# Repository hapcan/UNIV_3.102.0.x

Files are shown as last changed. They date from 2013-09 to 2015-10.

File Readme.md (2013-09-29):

UNIV 3.102.0.x
============

ETHERNET INTERFACE - interface to devices with Ethernet port (server mode)

Device webpage: http://hapcan.com/devices/universal/univ_3/univ_3-102-0-x/

Hardware created in Eagle PCB Software http://www.cadsoftusa.com/

Firmware created in Microchip MPLAB http://www.microchip.com/mplabide/ in assembly language
                 and
                 in Tibbo IDE http://tibbo.com/basic/product/tide.html in Tibbo Basic language

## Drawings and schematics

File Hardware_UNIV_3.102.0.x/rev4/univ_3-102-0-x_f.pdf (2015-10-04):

## ETHERNET INTERFACE

# UNIV 3.102.0.x

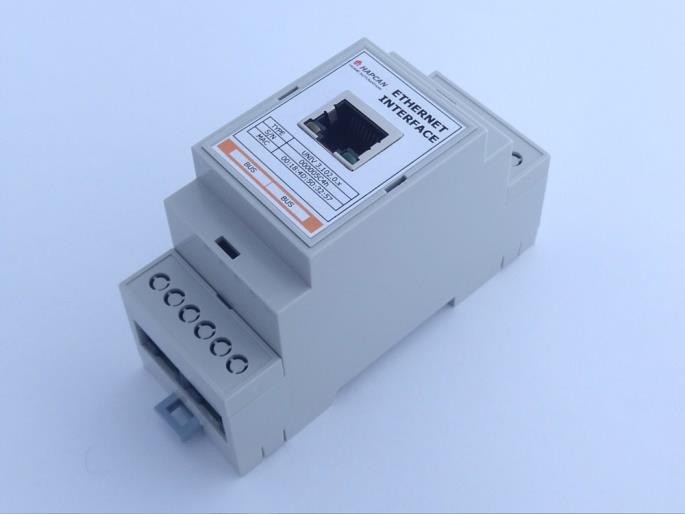
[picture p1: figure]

© 2014 hapcan.com | univ_3-102-0-x_f.pdf - page 1 / 5

### 1. Features

- Ethernet interface for HAPCAN system.
- Uses Tibbo miniature programmable Ethernet EM500 module
- 512kB build into Tibbo module and 1MB external flash memory for firmware; 200 bytes of EEPROM space for data storage
- Supports 10/100BaseTX
- Supports auto-MDIX
- Build in Real Time Clock
- Operation voltage 10-24V
- Current consumption 60mA
- For DIN rail mounting.
- Dimensions 90x58x36 mm (2 mod)
- Operating of module depends on firmwares uploaded into it (Tibbo and UNIV 3 firmwares)

### 2. Application version

UNIV | 3 | . | 102 | . | 0 | . | x
firmware version
application version
application type (Ethernet interface) processor version
universal processor

### 3. Technical data

Bus side
Parameter | Symbol | Value | Unit
Power supply voltage | Us | 10-24V | V
Current consumption | Is | 150@10V, 60@24V | mA
Bus connector type | 2x RJ45 connectors

Ethernet port side
Parameter | Unit
Connector | RJ45 auto-MDIX
Status LEDs | Bright LEDs flashing means active 10/100BaseTX link. Flashing patterns depend on firmware installed in Tibbo

### 4. Hardware

### 4.1. Wiring

1 - Tx+
2 - Tx-3 - Rx+
4 - NC

5 - NC
6 - Rx-7 - NC
8 - NC

Note that if module is first or last on the bus,
resistor 120ohm must be connected between pins CAN H and CAN L.
Figure 1. RJ45 10/100 BaseTX Ethernet connector. | Figure 2. RJ45 bus connector.
1 | 8
1 | 8
1 | 8

1 – white/orange - CAN H
2 – orange - CAN L
3 – white/green - NC
4 – blue – CAN V+
5 – white/blue – CAN GND
6 – green - NC
7 – white/brown – CAN GND
8 – brown – CAN V+

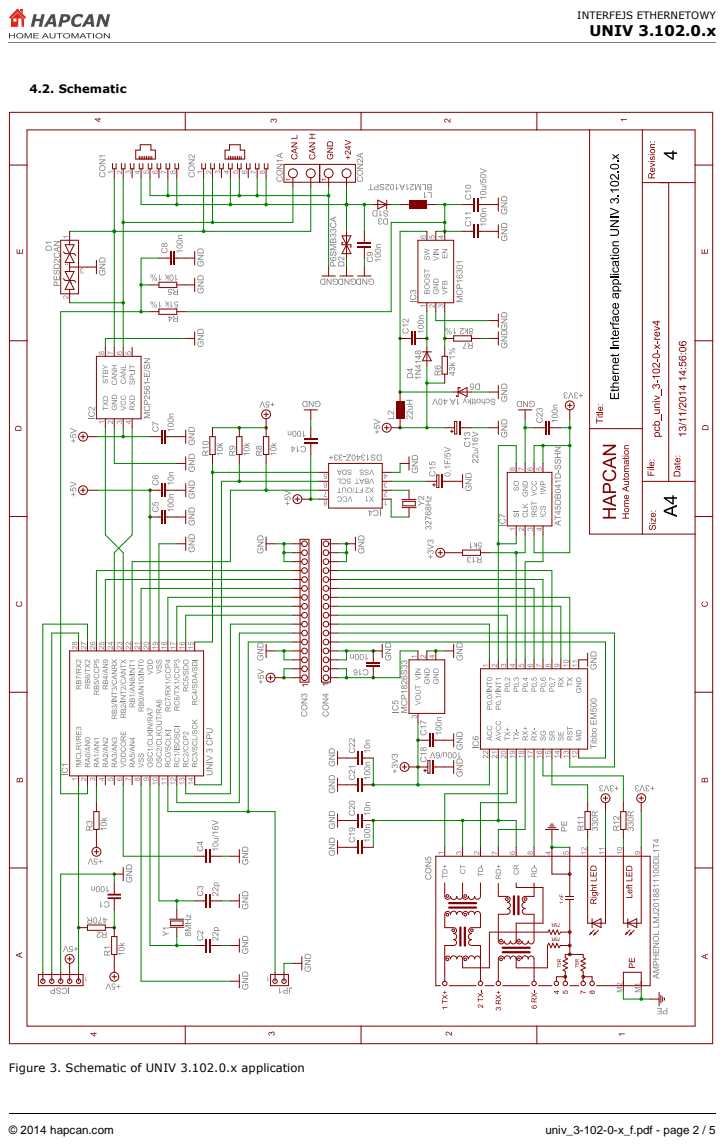
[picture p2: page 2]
INTERFEJS ETHERNETOWY; 4.2. Schematic

Figure 3. Schematic of UNIV 3.102.0.x application

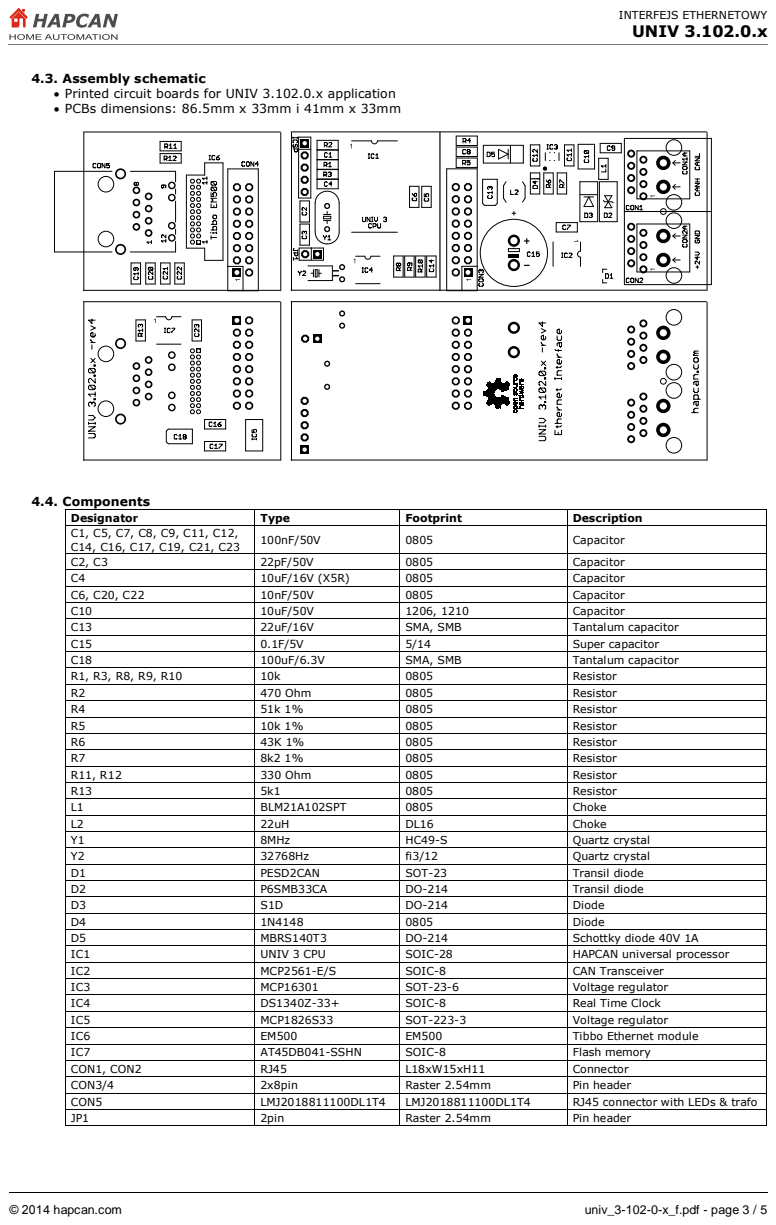
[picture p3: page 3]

4.3. Assembly schematic
• Printed circuit boards for UNIV 3.102.0.x application
• PCBs dimensions: 86.5mm x 33mm i 41mm x 33mm

Designator | Type | Footprint | Description
C1, C5, C7, C8, C9, C11, C12, C14, C16, C17, C19, C21, C23 | 100nF/50V | 0805 | Capacitor

C2, C3 | 22pF/50V | 0805 | Capacitor
C4 | 10uF/16V (X5R) | 0805 | Capacitor
C6, C20, C22 | 10nF/50V | 0805 | Capacitor
C10 | 10uF/50V | 1206, 1210 | Capacitor
C13 | 22uF/16V | SMA, SMB | Tantalum capacitor
C15 | 0.1F/5V | 5/14 | Super capacitor
C18 | 100uF/6.3V | SMA, SMB | Tantalum capacitor
R1, R3, R8, R9, R10 | 10k | 0805 | Resistor
R2 | 470 Ohm | 0805 | Resistor
R4 | 51k 1% | 0805 | Resistor
R5 | 10k 1% | 0805 | Resistor
R6 | 43K 1% | 0805 | Resistor
R7 | 8k2 1% | 0805 | Resistor
R11, R12 | 330 Ohm | 0805 | Resistor
R13 | 5k1 | 0805 | Resistor
L1 | BLM21A102SPT | 0805 | Choke
L2 | 22uH | DL16 | Choke
Y1 | 8MHz | HC49-S | Quartz crystal
Y2 | 32768Hz | fi3/12 | Quartz crystal
D1 | PESD2CAN | SOT-23 | Transil diode
D2 | P6SMB33CA | DO-214 | Transil diode
D3 | S1D | DO-214 | Diode
D4 | 1N4148 | 0805 | Diode
D5 | MBRS140T3 | DO-214 | Schottky diode 40V 1A
IC1 | UNIV 3 CPU | SOIC-28 | HAPCAN universal processor
IC2 | MCP2561-E/S | SOIC-8 | CAN Transceiver
IC3 | MCP16301 | SOT-23-6 | Voltage regulator
IC4 | DS1340Z-33+ | SOIC-8 | Real Time Clock
IC5 | MCP1826S33 | SOT-223-3 | Voltage regulator
IC6 | EM500 | EM500 | Tibbo Ethernet module
IC7 | AT45DB041-SSHN | SOIC-8 | Flash memory
CON1, CON2 | RJ45 | L18xW15xH11 | Connector
CON3/4 | 2x8pin | Raster 2.54mm | Pin header
CON5 | LMJ2018811100DL1T4 | LMJ2018811100DL1T4 | RJ45 connector with LEDs & trafo
JP1 | 2pin | Raster 2.54mm | Pin header

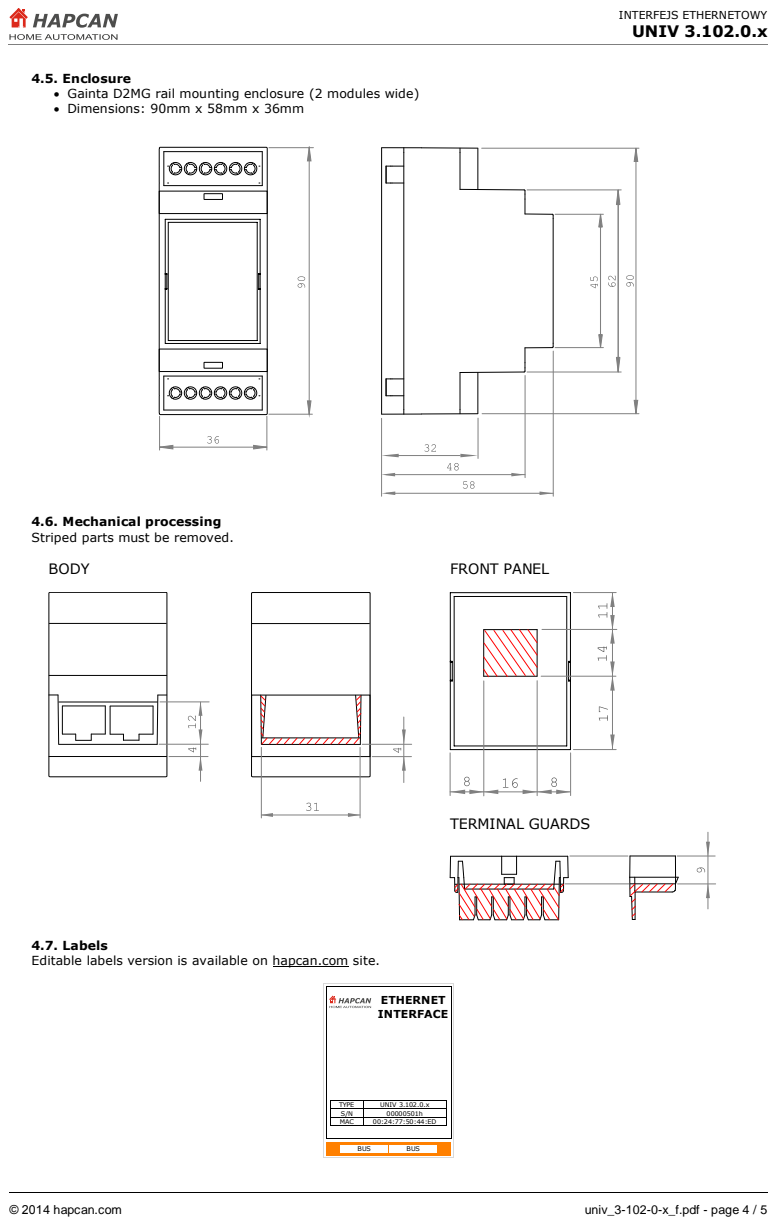
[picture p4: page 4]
BODY; FRONT PANEL; TERMINAL GUARDS; ETHERNET INTERFACE; BUS

4.5. Enclosure
• Gainta D2MG rail mounting enclosure (2 modules wide)
• Dimensions: 90mm x 58mm x 36mm

4.6. Mechanical processing
Striped parts must be removed.

4.7. Labels
Editable labels version is available on hapcan.com site.

TYPE | UNIV 3.102.0.x
S/N | 00000501h
MAC | 00:24:77:50:44:ED

### 5. Commissioning

### 5.1. CPU voltage measurement

After verifying the correctness and quality of the soldering, the bus voltage should be connected while measuring the processor voltage. To do this, connect a voltmeter to pins 2 and 3 of the ICSP connector. Processor supply voltage should be about 5V.

Figure 4. CPU voltage measurement
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

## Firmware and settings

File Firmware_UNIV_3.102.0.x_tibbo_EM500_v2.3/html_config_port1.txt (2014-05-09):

bit0	multi-port configuration
bit1	multi-channel configuration
bit2	Power on pin 9 available
bit3	Wi-Fi available
bit4	GPRS available
bit5	serial port modes are 232, 485, and 422
bit6	serial port modes are full-duplex and half-duples
bit7	serial port supports baudrates up to 115200	
bit8	serial port supports all baudrates

bits876543210

>>&b000000000	CT	Connection Timeout [min]						S,I,2	^
>>&b000000000	MO	Working Mode 									B,L,0-Single Socket Mode;1-Multi Socket Mode;	^
>>&b000000000	P0	Web Port										S,I,5	^
>>&b000000000	P1	Port of Socket 1								S,I,5	^

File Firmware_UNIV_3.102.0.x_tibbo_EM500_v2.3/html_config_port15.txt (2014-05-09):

bit0	multi-port configuration
bit1	multi-channel configuration
bit2	Power on pin 9 available
bit3	Wi-Fi available
bit4	GPRS available
bit5	serial port modes are 232, 485, and 422
bit6	serial port modes are full-duplex and half-duples
bit7	serial port supports baudrates up to 115200	
bit8	serial port supports all baudrates

bits876543210

>>&b000000000	CT	Connection Timeout [min]						S,I,2	^
>>&b000000000	MO	Working Mode 									B,L,0-Single Socket Mode;1-Multi Socket Mode;	^
>>&b000000000	P0	Web Port										S,I,5	^
>>&b000000000	P1	<b>Socket 1</b> - Port 							S,I,5	^
>>&b000000000	P2	<b>Socket 2</b> - Port							S,I,5	^
>>&b000000000	B2	- Block programming messages					B,L,0-No;1-Yes;	^
>>&b000000000	P3	<b>Socket 3</b> - Port							S,I,5	^
>>&b000000000	B3	- Block programming messages					B,L,0-No;1-Yes;	^
>>&b000000000	P4	<b>Socket 4</b> - Port							S,I,5	^
>>&b000000000	B4	- Block programming messages					B,L,0-No;1-Yes;	^
>>&b000000000	P5	<b>Socket 5</b> - Port							S,I,5	^
>>&b000000000	B5	- Block programming messages					B,L,0-No;1-Yes;	^
>>&b000000000	P6	<b>Socket 6</b> - Port							S,I,5	^
>>&b000000000	B6	- Block programming messages					B,L,0-No;1-Yes;	^
>>&b000000000	P7	<b>Socket 7</b> - Port							S,I,5	^
>>&b000000000	B7	- Block programming messages					B,L,0-No;1-Yes;	^
>>&b000000000	P8	<b>Socket 8</b> - Port							S,I,5	^
>>&b000000000	B8	- Block programming messages					B,L,0-No;1-Yes;	^
>>&b000000000	P9	<b>Socket 9</b> - Port							S,I,5	^
>>&b000000000	B9	- Block programming messages					B,L,0-No;1-Yes;	^
>>&b000000000	PA	<b>Socket 10</b> - Port							S,I,5	^
>>&b000000000	BA	- Block programming messages					B,L,0-No;1-Yes;	^
>>&b000000000	PB	<b>Socket 11</b> - Port							S,I,5	^
>>&b000000000	BB	- Block programming messages					B,L,0-No;1-Yes;	^
>>&b000000000	PC	<b>Socket 12</b> - Port							S,I,5	^
>>&b000000000	BC	 Block programming messages						B,L,0-No;1-Yes;	^
>>&b000000000	PD	<b>Socket 13</b> - Port							S,I,5	^
>>&b000000000	BD	- Block programming messages					B,L,0-No;1-Yes;	^
>>&b000000000	PE	<b>Socket 14</b> - Port							S,I,5	^
>>&b000000000	BE	- Block programming messages					B,L,0-No;1-Yes;	^

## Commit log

2013-09-26 hardware revision 2
    [univ_3-102-0-x-rev2.brd, univ_3-102-0-x-rev2.sch]
2013-09-26 firmware tibbo v1.0
    [html_config_gprs.txt, html_config_ports.txt, html_config_settings.txt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]
2013-09-26 firmware tibbo v2.0
    [html_config_port1.txt, html_config_port15.txt, html_config_settings.txt]
2013-11-26 firmware revision 0
    [univ_3-102-0-1-rev0-memory.xls]
2014-02-26 hardware revision 3
    [pcb_univ_3-102-0-x-rev2.brd, pcb_univ_3-102-0-x-rev2.sch, pcb_univ_3-102-0-x-rev3.brd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]
2014-05-09 firmware UNIV 3.102.0.1-rev1
    [univ_3-102-0-1-rev1-memory.xls]
2014-05-09 firmware tibbo v2.1
    [html_config_port1.txt, html_config_port15.txt, html_config_settings.txt]
2015-10-04 hardware UNIV 3.102.0.x rev2
    [pcb_univ_3-102-0-x-rev2.brd, pcb_univ_3-102-0-x-rev2.sch]
2015-10-04 hardware UNIV 3.102.0.x rev3
    [pcb_univ_3-102-0-x-rev3.brd, pcb_univ_3-102-0-x-rev3.sch]
2015-10-04 hardware UNIV 3.102.0.x rev4
    [pcb_univ_3-102-0-x-rev4.brd, pcb_univ_3-102-0-x-rev4.sch]
2015-10-04 firmware UNIV 3.102.0.1-rev2
    [univ_3-102-0-1-rev2-memory.xls]
2016-12-30 firmware UNIV 3.102.0.1 revision 3
    [univ_3-102-0-1-rev3-memory.xls]
2018-03-27 firmware tibbo v2.2
    [html_config_port1.txt, html_config_port15.txt, html_config_settings.txt]
2018-03-28 firmware tibbo v2.3
    [html_config_port1.txt, html_config_port15.txt, html_config_settings.txt]

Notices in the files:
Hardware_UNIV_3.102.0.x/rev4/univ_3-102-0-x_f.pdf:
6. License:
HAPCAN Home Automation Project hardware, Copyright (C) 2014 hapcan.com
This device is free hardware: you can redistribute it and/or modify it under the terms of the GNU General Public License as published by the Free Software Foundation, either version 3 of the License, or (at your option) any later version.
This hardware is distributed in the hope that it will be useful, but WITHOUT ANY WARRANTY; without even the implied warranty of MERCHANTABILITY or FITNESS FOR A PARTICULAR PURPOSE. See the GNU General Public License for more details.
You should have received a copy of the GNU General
